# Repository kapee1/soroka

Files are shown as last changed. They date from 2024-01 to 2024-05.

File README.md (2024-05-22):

# soroka - DIY-Friendly 40% keyboard

> Important: Currently working on version v2 with many minor fixes.
It won't be compatible with v1, but I'll keep all files for v1.



### Main features:

* Easy to build. Great for soldering practice.
* Supports all cyrillic symbols in base layer.
* Compatible with most base-kit keycap sets. No 40s addons needed.
* Optional EC-11 encoder
* Plate also optional. You can build keyboard without a plate to reduce cost.
* Variable bottom-row with a 3u spacebars support.
* Customizable panels
* VIAL/QMK 

### Layout:



### Known issues:
* Hole for USB port should be bigger to prevent any interference (fixed in v2)
* Diodes on bottom row touches case mount.. (fixed in v2)
* The screw holes in plate are inconvenient. Replaced by slots in v2

BOM (and iBOM in soroka-pcb/bom/ibom.html)
| Part | Quantity |  Link |
|---|---|---|
| Soroka PCB  | 1 |  - |
| Soroka Plate (Optional)  |  1 |  - |
| Soroka Case | 1 |  - |
| Soroka Panel  |  1 |  - |
| RP2040-Zero  | 1 |  [Aliexpress](https://aliexpress.ru/item/1005004281549886.html) |
| 1N4148 SOD-123 Diode T4 1206  | 50  |  [Aliexpress](https://aliexpress.ru/item/1005005271390029.html) |
| EC-11 Encoder 12.5mm (optional)  |  1 |  [Aliexpress](https://aliexpress.ru/item/32976046900.html) |
| Round silicon feets 8x8x0.5| 4  |  - |
| M2 x 4mm Screws  | 15  |  [Aliexpress](https://aliexpress.ru/item/4000896301219.html) |
| M2 Inserts 3mm (OD3.2) | 7 |  [Aliexpress](https://aliexpress.ru/item/1005003582355741.htm) |
| Female-Female Standoffs 10mm | 4  |  [Aliexpress](https://aliexpress.ru/item/1005004469963266.html) |

### Some photos:




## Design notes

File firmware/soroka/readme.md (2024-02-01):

# soroka

soroka

* Keyboard Maintainer: [kapee1](https://github.com/kapee1)

Make example for this keyboard (after setting up your build environment):

    make soroka:default

Flashing example for this keyboard:

    make soroka:default:flash

See the [build environment setup](https://docs.qmk.fm/#/getting_started_build_tools) and the [make instructions](https://docs.qmk.fm/#/getting_started_make_guide) for more information. Brand new to QMK? Start with our [Complete Newbs Guide](https://docs.qmk.fm/#/newbs).

## Bootloader

Enter the bootloader in 3 ways:

* **Bootmagic reset**: Hold down the key at (0,0) in the matrix (usually the top left key or Escape) and plug in the keyboard
* **Physical reset button**: Briefly press the button on the back of the PCB - some may have pads you must short instead
* **Keycode in layout**: Press the key mapped to `QK_BOOT` if it is available

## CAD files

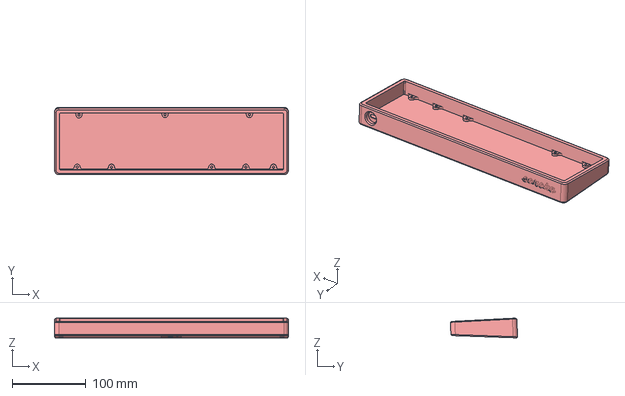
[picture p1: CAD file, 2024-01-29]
case/soroka_6degree_(untested).step
317.2 x 91.4 x 26.8 mm

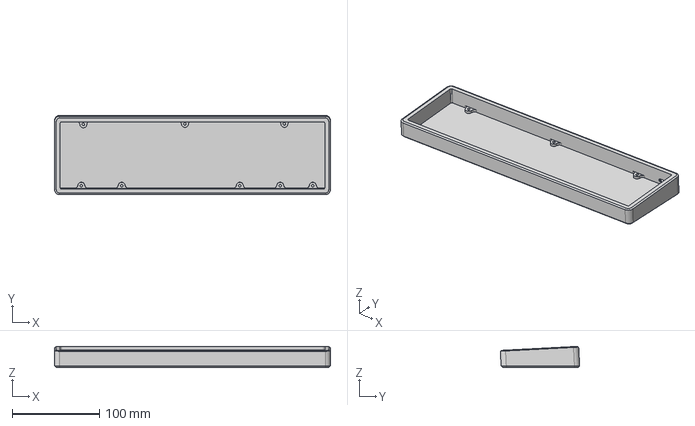
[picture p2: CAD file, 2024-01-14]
case/soroka-v1.step
317.2 x 91.2 x 24.4 mm

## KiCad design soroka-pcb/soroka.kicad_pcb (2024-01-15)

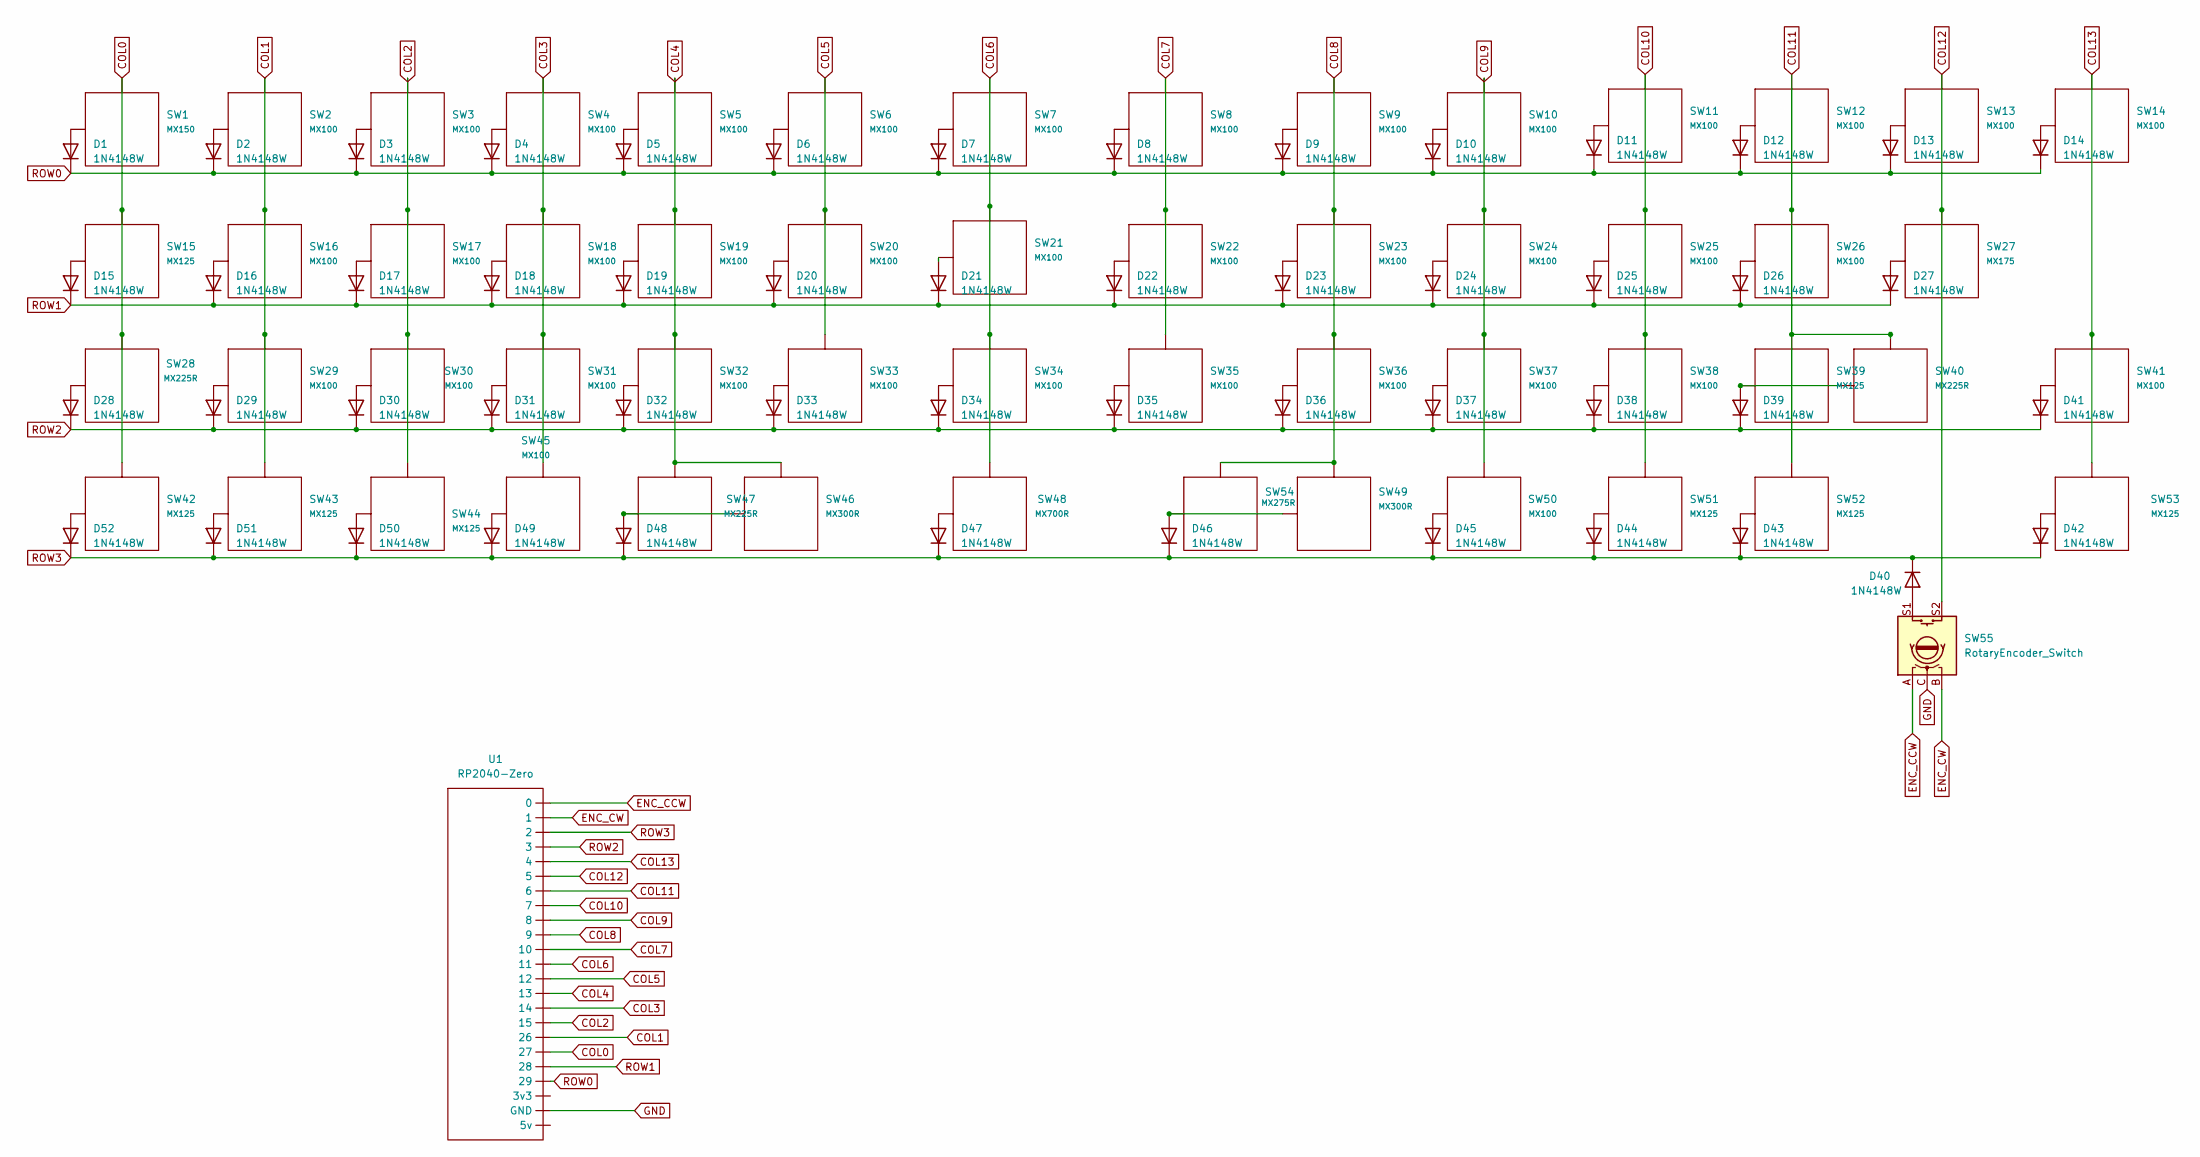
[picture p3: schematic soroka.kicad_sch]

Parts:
D1, D2, D3, D4, D5, D6, D7, D8, D9, D10, D11, D12, D13, D14, D15, D16, D17, D18, D19, D20, D21, D22, D23, D24, D25, D26, D27, D28, D29, D30, D31, D32, D33, D34, D35, D36, D37, D38, D39, D40, D41, D42, D43, D44, D45, D46, D47, D48, D49, D50, D51, D52: 1N4148W; D_SOD-123
SW1: MX150
SW2, SW3, SW4, SW5, SW6, SW7, SW8, SW9, SW10, SW11, SW12, SW13, SW14, SW16, SW17, SW18, SW19, SW20, SW21, SW22, SW23, SW24, SW25, SW26, SW29, SW30, SW31, SW32, SW33, SW34, SW35, SW36, SW37, SW38, SW41, SW45, SW50: MX100
SW15, SW39, SW42, SW43, SW44, SW51, SW52, SW53: MX125
SW27: MX175
SW28, SW40: MX225R; MX225
SW46, SW49: MX300R
SW47: MX225R
SW48: MX700R
SW54: MX275R
SW55: RotaryEncoder_Switch; RotaryEncoder_Alps_EC11E-Switch_Vertical_H20mm
U1: RP2040-Zero; MCU_rp2040-zero-smd

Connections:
COL0: SW1.2 (Row), SW15.2 (Row), SW28.2 (Row), SW42.2 (Row), U1.27; also elsewhere on the board
COL1: SW2.2 (Row), SW16.2 (Row), SW29.2 (Row), SW43.2 (Row), U1.26
COL2: SW3.2 (Row), SW17.2 (Row), SW30.2 (Row), SW44.2 (Row), U1.15
COL3: SW4.2 (Row), SW18.2 (Row), SW31.2 (Row), SW45.2 (Row), U1.14
COL4: SW5.2 (Row), SW19.2 (Row), SW32.2 (Row), SW46.2 (Row), SW47.2 (Row), U1.13
COL5: SW6.2 (Row), SW20.2 (Row), SW33.2 (Row), U1.12
COL6: SW7.2 (Row), SW21.2 (Row), SW34.2 (Row), SW48.2 (Row), U1.11
COL7: SW8.2 (Row), SW22.2 (Row), SW35.2 (Row), U1.10
COL8: SW9.2 (Row), SW23.2 (Row), SW36.2 (Row), SW49.2 (Row), SW54.2 (Row), U1.9
COL9: SW10.2 (Row), SW24.2 (Row), SW37.2 (Row), SW50.2 (Row), U1.8
COL10: SW11.2 (Row), SW25.2 (Row), SW38.2 (Row), SW51.2 (Row), U1.7
COL11: SW12.2 (Row), SW26.2 (Row), SW39.2 (Row), SW40.2 (Row), SW52.2 (Row), U1.6
COL12: SW13.2 (Row), SW27.2 (Row), SW55.S2, U1.5
COL13: SW14.2 (Row), SW41.2 (Row), SW53.2 (Row), U1.4
ENC_CCW: SW55.A, U1.0
ENC_CW: SW55.B, U1.1
GND: SW55.C, U1.GND
unnamed: D1.2 (A), SW1.1 (Col)
unnamed: D2.2 (A), SW2.1 (Col)
unnamed: D3.2 (A), SW3.1 (Col)
unnamed: D4.2 (A), SW4.1 (Col)
unnamed: D5.2 (A), SW5.1 (Col)
unnamed: D6.2 (A), SW6.1 (Col)
unnamed: D7.2 (A), SW7.1 (Col)
unnamed: D8.2 (A), SW8.1 (Col)
unnamed: D9.2 (A), SW9.1 (Col)
unnamed: D10.2 (A), SW10.1 (Col)
unnamed: D11.2 (A), SW11.1 (Col)
unnamed: D12.2 (A), SW12.1 (Col)
unnamed: D13.2 (A), SW13.1 (Col)
unnamed: D14.2 (A), SW14.1 (Col)
unnamed 31: D15.2 (A), SW15.1 (Col); also elsewhere on the board
unnamed: D16.2 (A), SW16.1 (Col)
unnamed: D17.2 (A), SW17.1 (Col)
unnamed: D18.2 (A), SW18.1 (Col)
unnamed: D19.2 (A), SW19.1 (Col)
unnamed: D20.2 (A), SW20.1 (Col)
unnamed: D21.2 (A), SW21.1 (Col)
unnamed: D22.2 (A), SW22.1 (Col)
unnamed: D23.2 (A), SW23.1 (Col)
unnamed: D24.2 (A), SW24.1 (Col)
unnamed: D25.2 (A), SW25.1 (Col)
unnamed: D26.2 (A), SW26.1 (Col)
unnamed: D27.2 (A), SW27.1 (Col)
unnamed: D28.2 (A), SW28.1 (Col)
unnamed: D29.2 (A), SW29.1 (Col)
unnamed: D30.2 (A), SW30.1 (Col)
unnamed: D31.2 (A), SW31.1 (Col)
unnamed: D32.2 (A), SW32.1 (Col)
unnamed: D33.2 (A), SW33.1 (Col)
unnamed: D34.2 (A), SW34.1 (Col)
unnamed: D35.2 (A), SW35.1 (Col)
unnamed: D36.2 (A), SW36.1 (Col)
unnamed: D37.2 (A), SW37.1 (Col)
unnamed: D38.2 (A), SW38.1 (Col)
unnamed: D39.2 (A), SW39.1 (Col), SW40.1 (Col)
unnamed: D40.2 (A), SW55.S1
unnamed: D41.2 (A), SW41.1 (Col)
unnamed: D42.2 (A), SW53.1 (Col)
unnamed: D43.2 (A), SW52.1 (Col)
unnamed: D44.2 (A), SW51.1 (Col)
unnamed: D45.2 (A), SW50.1 (Col)
unnamed: D46.2 (A), SW49.1 (Col), SW54.1 (Col)
unnamed: D47.2 (A), SW48.1 (Col)
unnamed: D48.2 (A), SW46.1 (Col), SW47.1 (Col)
unnamed: D49.2 (A), SW45.1 (Col)
unnamed: D50.2 (A), SW44.1 (Col)
unnamed: D51.2 (A), SW43.1 (Col)
unnamed: D52.2 (A), SW42.1 (Col)
ROW0: D1.1 (K), D2.1 (K), D3.1 (K), D4.1 (K), D5.1 (K), D6.1 (K), D7.1 (K), D8.1 (K), D9.1 (K), D10.1 (K), D11.1 (K), D12.1 (K), D13.1 (K), D14.1 (K), U1.29
ROW1: D15.1 (K), D16.1 (K), D17.1 (K), D18.1 (K), D19.1 (K), D20.1 (K), D21.1 (K), D22.1 (K), D23.1 (K), D24.1 (K), D25.1 (K), D26.1 (K), D27.1 (K), U1.28
ROW2: D28.1 (K), D29.1 (K), D30.1 (K), D31.1 (K), D32.1 (K), D33.1 (K), D34.1 (K), D35.1 (K), D36.1 (K), D37.1 (K), D38.1 (K), D39.1 (K), D41.1 (K), U1.3
ROW3: D40.1 (K), D42.1 (K), D43.1 (K), D44.1 (K), D45.1 (K), D46.1 (K), D47.1 (K), D48.1 (K), D49.1 (K), D50.1 (K), D51.1 (K), D52.1 (K), U1.2

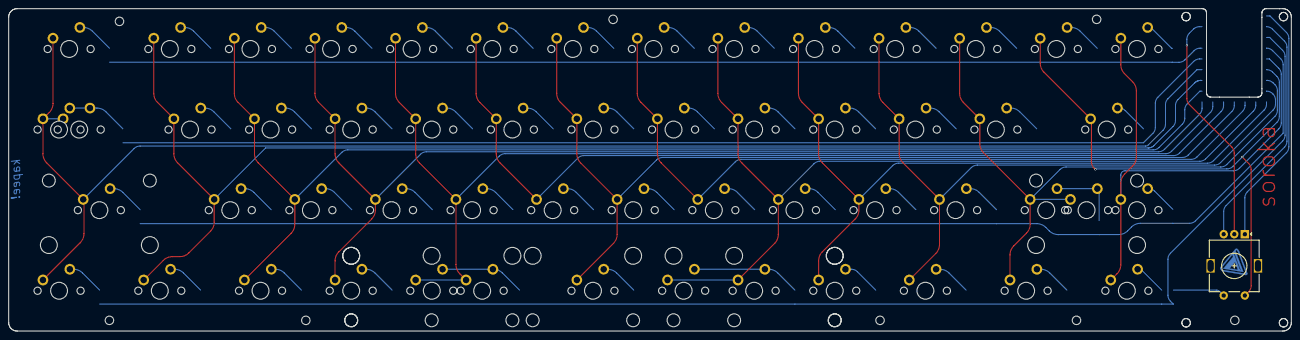
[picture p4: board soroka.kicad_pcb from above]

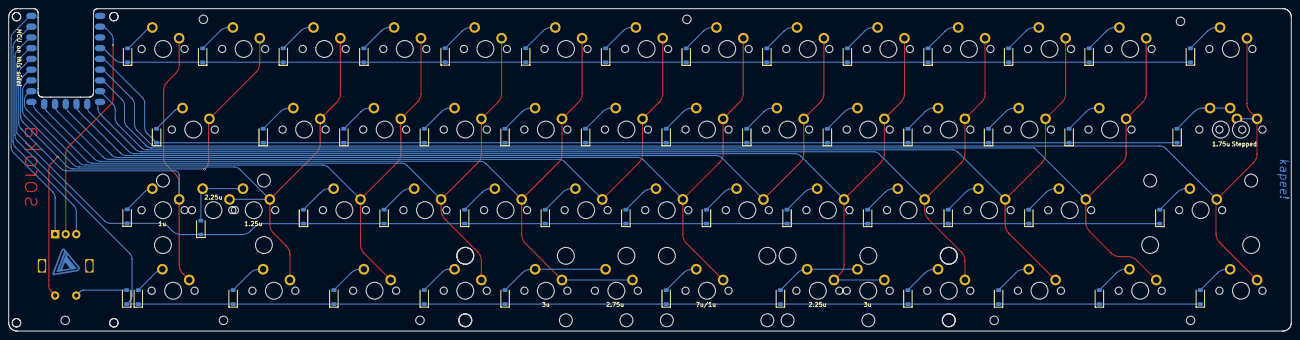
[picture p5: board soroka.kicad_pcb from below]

Board: 2 copper layers, 303.2 x 76.2 mm, 109 parts (54 on the bottom side), 73 nets.

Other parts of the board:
SW55#2: 1.75u; MX175

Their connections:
COL0: SW55#2.2; also elsewhere on the board
unnamed 31: SW55#2.1; also elsewhere on the board

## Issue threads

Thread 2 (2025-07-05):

New Hotswap PCB version - changed diode footprint?

XBMAX, 2025-07-05:
Can you please update the part list and mention the footprint change for the HS PCB versions diodes? They seem to be 3-pin now instead of the usual 2-pin from prior versions.

The part list also doesn't mention this change or a part ID. I was about to order some of these Hotswap PCB's and just ran across that. I'd hate for others to buy components and such and then realize they bought the wrong type just in case!

Greatly appreciated and thanks for the cool keyboard / sharing the files.

- Blake

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

kapee1, 2025-07-06:
Thank you very much, Blake!
Updated BOMs in the readme file. Be careful, the HS version is still untested, so order at your own risk.

Closed 2025-07-06.

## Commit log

2024-01-14 added pcb, plate and case files
    [plate.kicad_pcb, soroka-v1.step, soroka.kicad_pcb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]
2024-01-15 fixed typo and created new production files
    [soroka.kicad_pcb]
2024-01-22 fixed stabs cutouts
    [plate.kicad_pcb]
2024-01-29 added 6-degree case
    [soroka_6degree_(untested).step]
